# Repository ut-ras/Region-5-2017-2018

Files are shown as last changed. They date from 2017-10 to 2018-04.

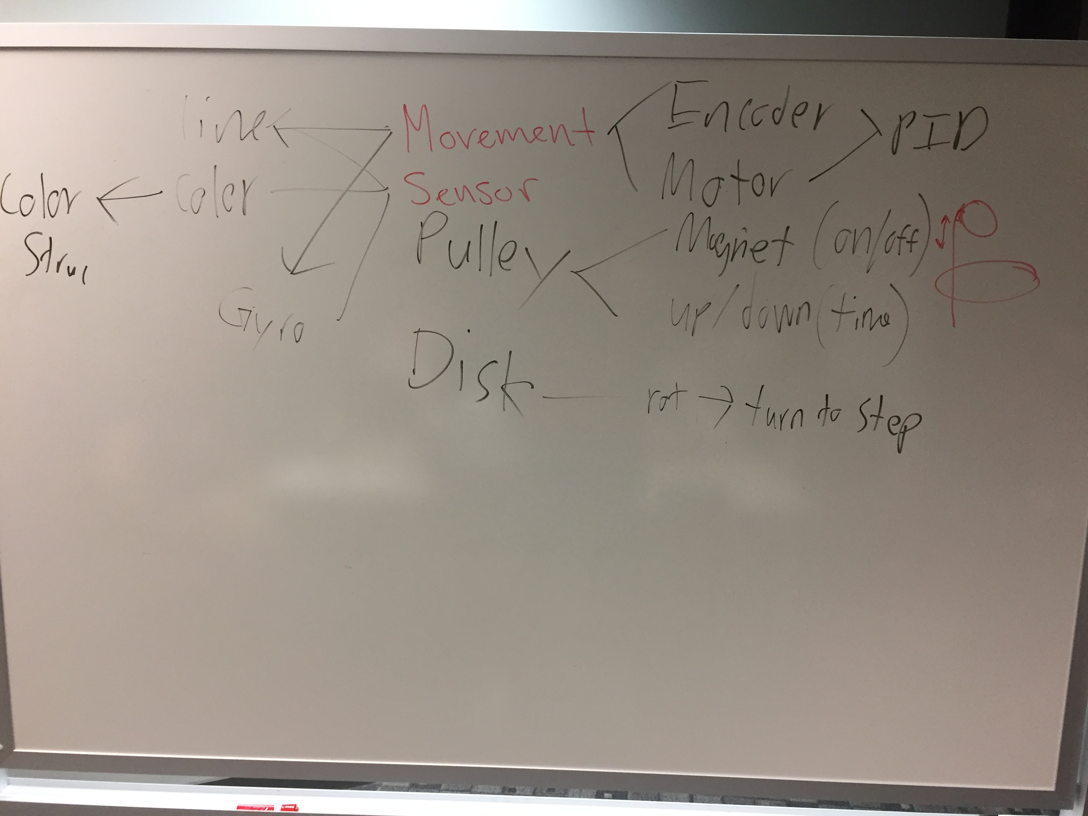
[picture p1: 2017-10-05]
notes/MeetingNotes.JPG

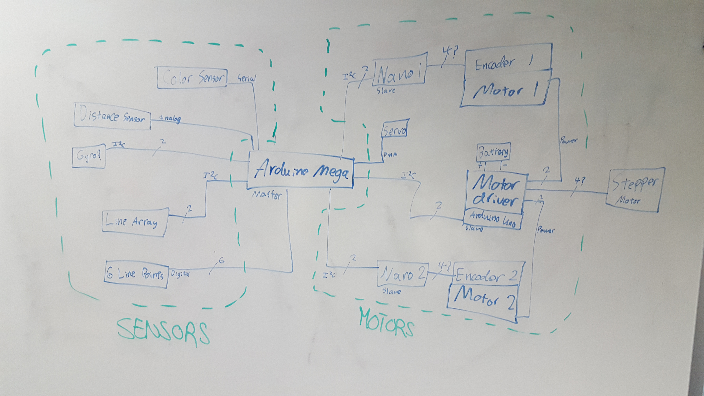
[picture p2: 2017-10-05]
notes/Systems diagram.jpg

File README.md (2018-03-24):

# Region 5 2017-2018
## [Region 5 Robotics Competition](http://r5conferences.org/competitions/robotics-competition/)

### This year we are using the Arduino IDE to program our microcontrollers.
#### [install link](https://www.arduino.cc/en/Main/Software)
#### To set up your laptop:
#### 0. Install the Arduino IDE
#### 1. Clone the Repository
#### 2. Add all the libraries in the ./src/librares/ folder through the arduino IDE
### The lead of Software is Cole Thompson

# Region-5-2017-2018

## WE'RE GONNA <s>WIN</s> MEME THIS YEAR FOLKS

## YEAH WE ARE!!!

## Groups
Drive System</br>
Line Following and Intersection Detection</br>
Token Control and Storage</br>
Field Mapping, Data Logging, and Debugging </br>

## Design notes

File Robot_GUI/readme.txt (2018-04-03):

Robot GUI

Note that an external jar is used, which is included in the jars folder.
Must be connected to Arduino to run.

To compile:
javac -cp ".:../jars/jSerialComm-1.3.11.jar" Robot_GUI.java

To run:
java -cp ".:../jars/jSerialComm-1.3.11.jar" Robot_GUI

This GUI accepts commands in the format of the node.toString() method.
It ignores anything else printed to Serial.

It can also write ints to Serial, however this functionality is untested.

[intersectionName:visited:tokenColor]
ex. [Y3:f:U]

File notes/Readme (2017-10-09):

***************************
*  October 4 - Wednesday  *
*  Header File Plan       *
***************************

Line Sensors
  6 points
     boolean
     
Stepper
  ? angle
  
2 Line
  boolean[8]
  
Ultrasound
  dist cm
  
RGB Sensor
  get a color cloest to...
    green
    red
    yellow
    cyan
    dark blue
    magenta
    
    black
    white
    gray
  
DC Motors
  adafruit motor controller
  speed
  direction
  time
  
Encoder
  # of ticks relative
  
IMU
  gyro
  acc
  compass

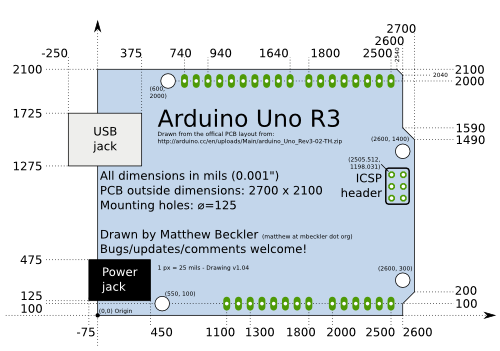
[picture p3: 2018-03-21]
electronics/arduino_uno_drawing_500x351.png

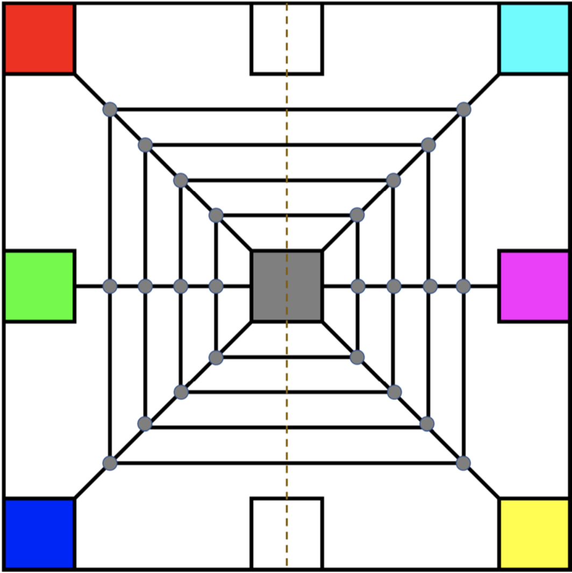
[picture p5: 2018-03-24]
Robot_GUI/playingfield.png

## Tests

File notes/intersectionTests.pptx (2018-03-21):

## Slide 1

Diagonals and Drop Points

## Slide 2

Reversed

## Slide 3

Inward Spiral (Edges)

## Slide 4

Outward Spiral (Edges)

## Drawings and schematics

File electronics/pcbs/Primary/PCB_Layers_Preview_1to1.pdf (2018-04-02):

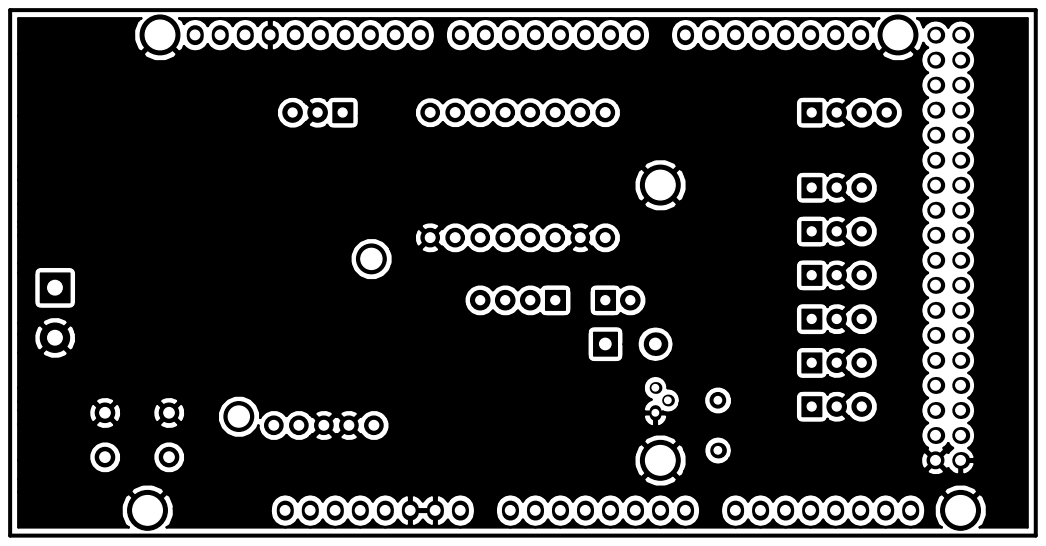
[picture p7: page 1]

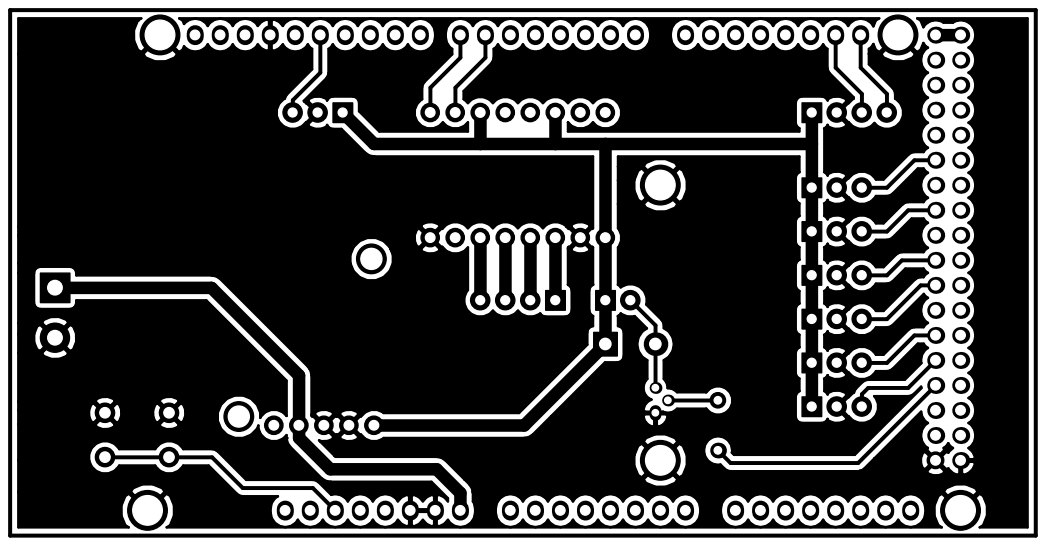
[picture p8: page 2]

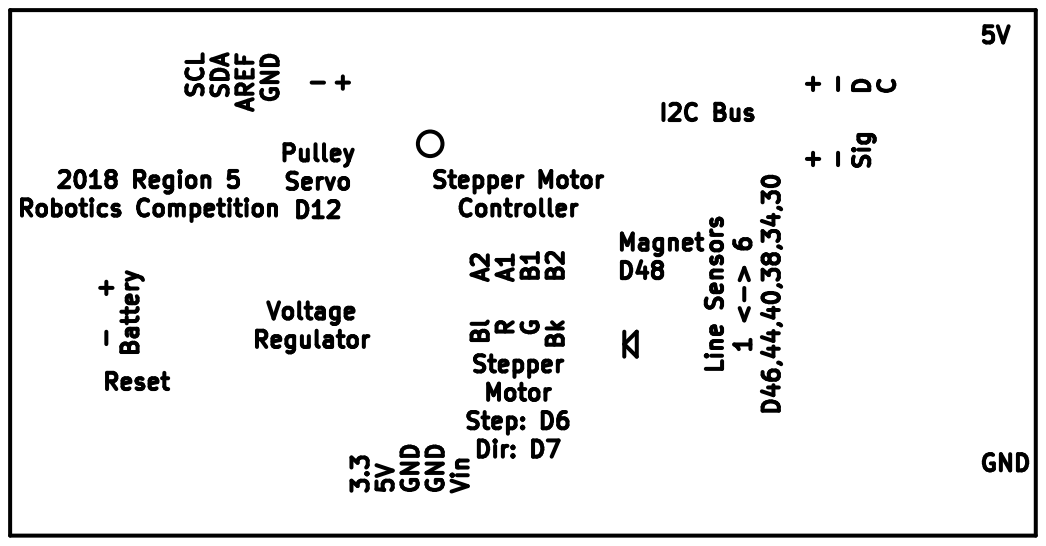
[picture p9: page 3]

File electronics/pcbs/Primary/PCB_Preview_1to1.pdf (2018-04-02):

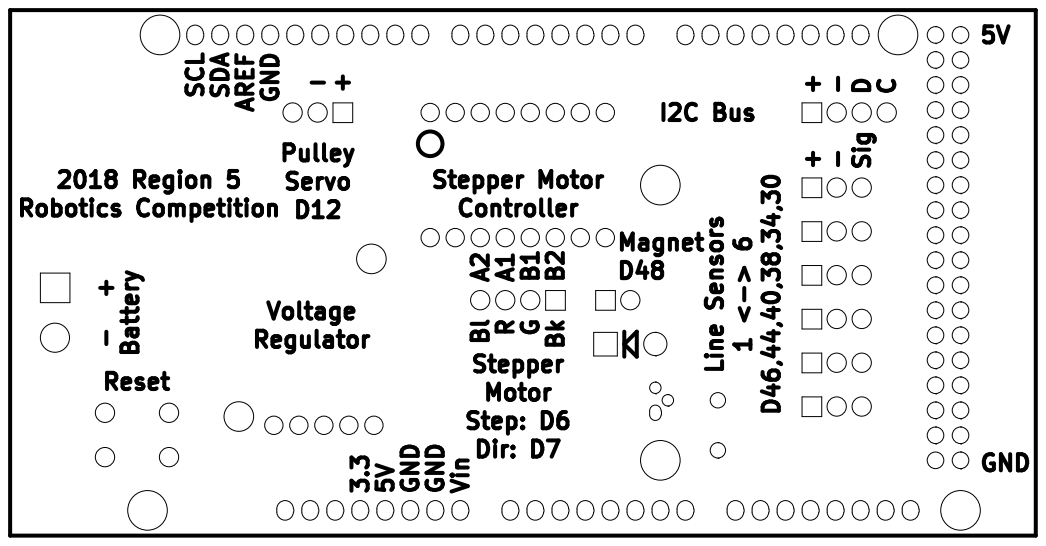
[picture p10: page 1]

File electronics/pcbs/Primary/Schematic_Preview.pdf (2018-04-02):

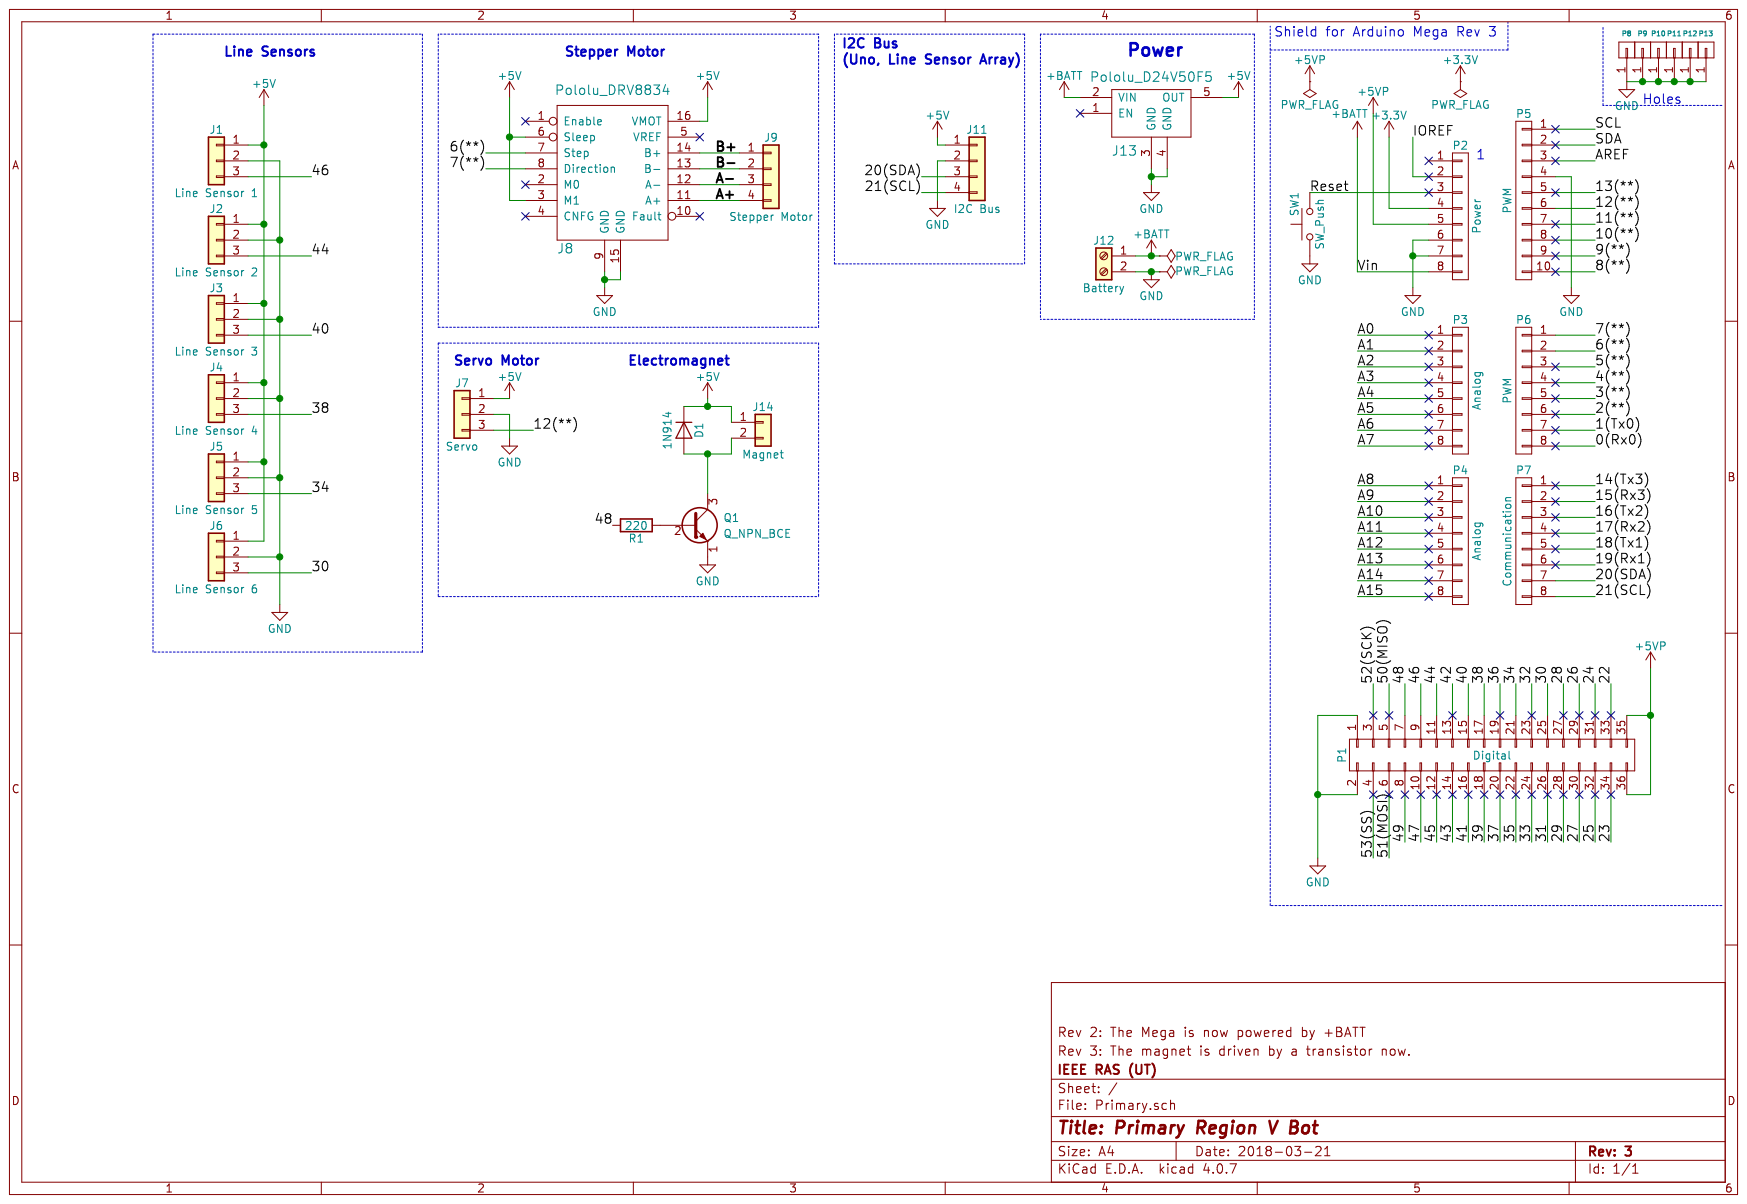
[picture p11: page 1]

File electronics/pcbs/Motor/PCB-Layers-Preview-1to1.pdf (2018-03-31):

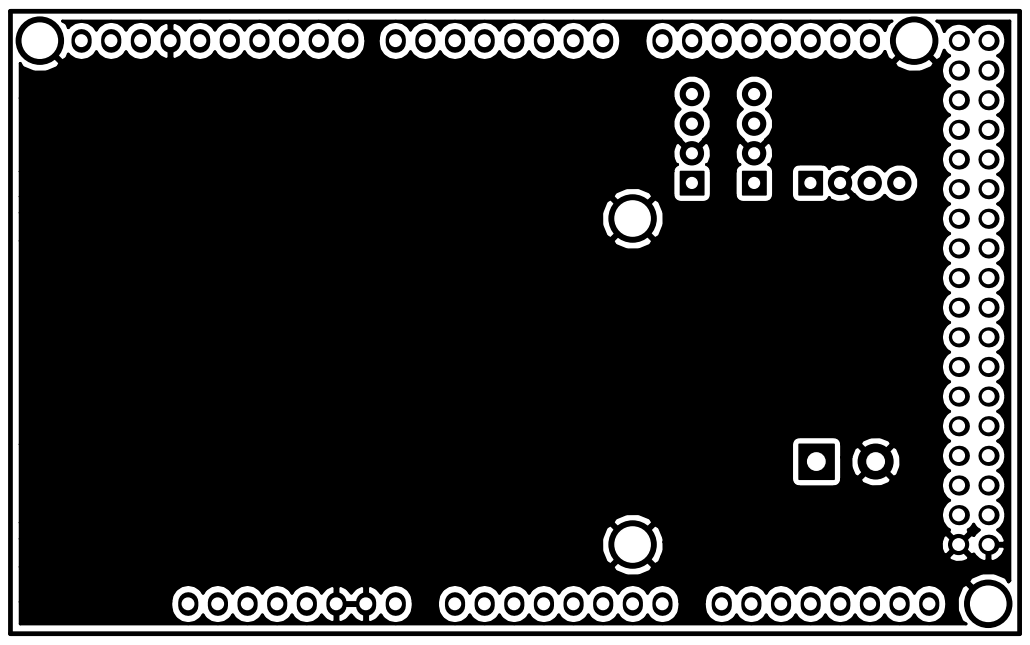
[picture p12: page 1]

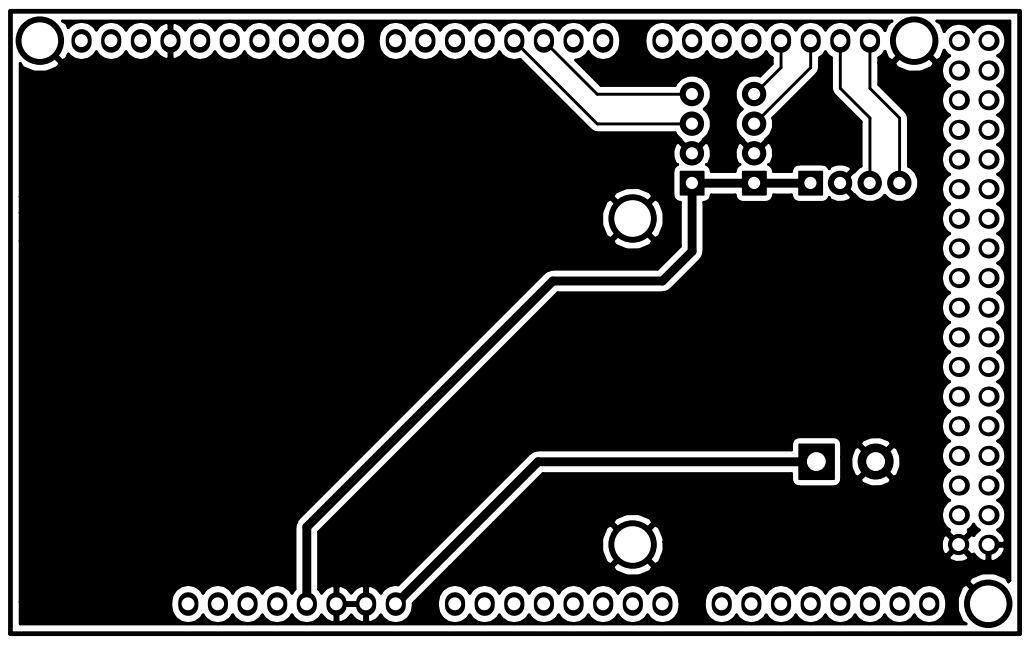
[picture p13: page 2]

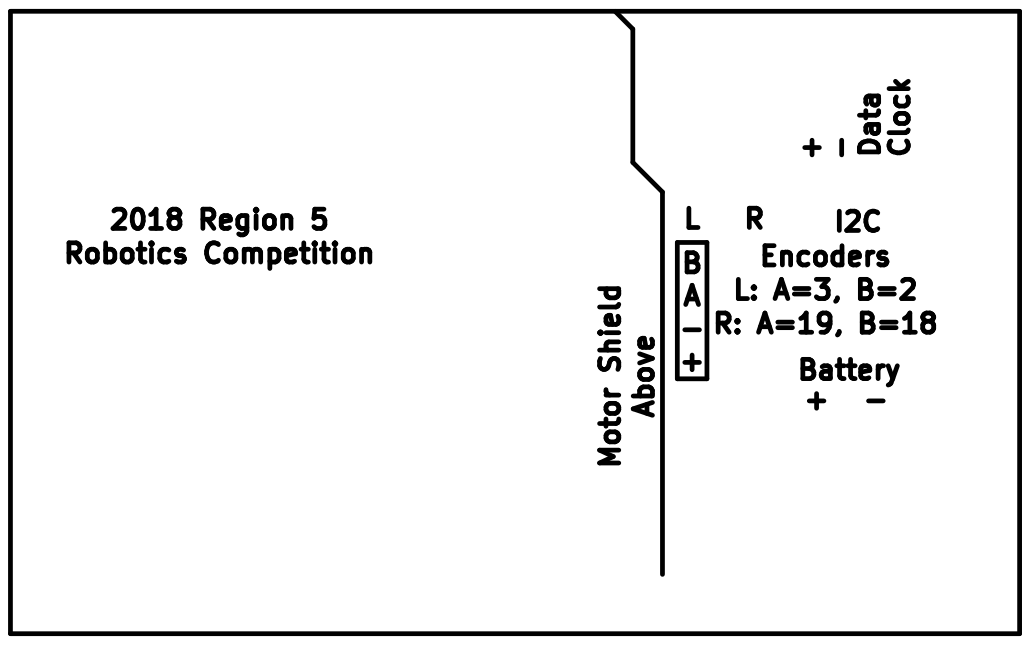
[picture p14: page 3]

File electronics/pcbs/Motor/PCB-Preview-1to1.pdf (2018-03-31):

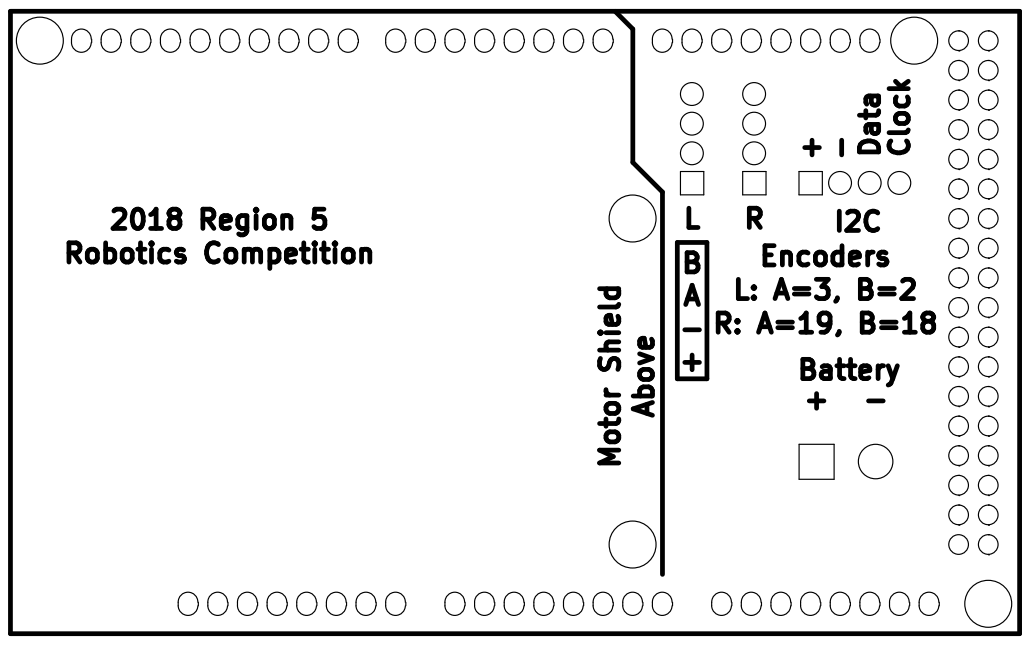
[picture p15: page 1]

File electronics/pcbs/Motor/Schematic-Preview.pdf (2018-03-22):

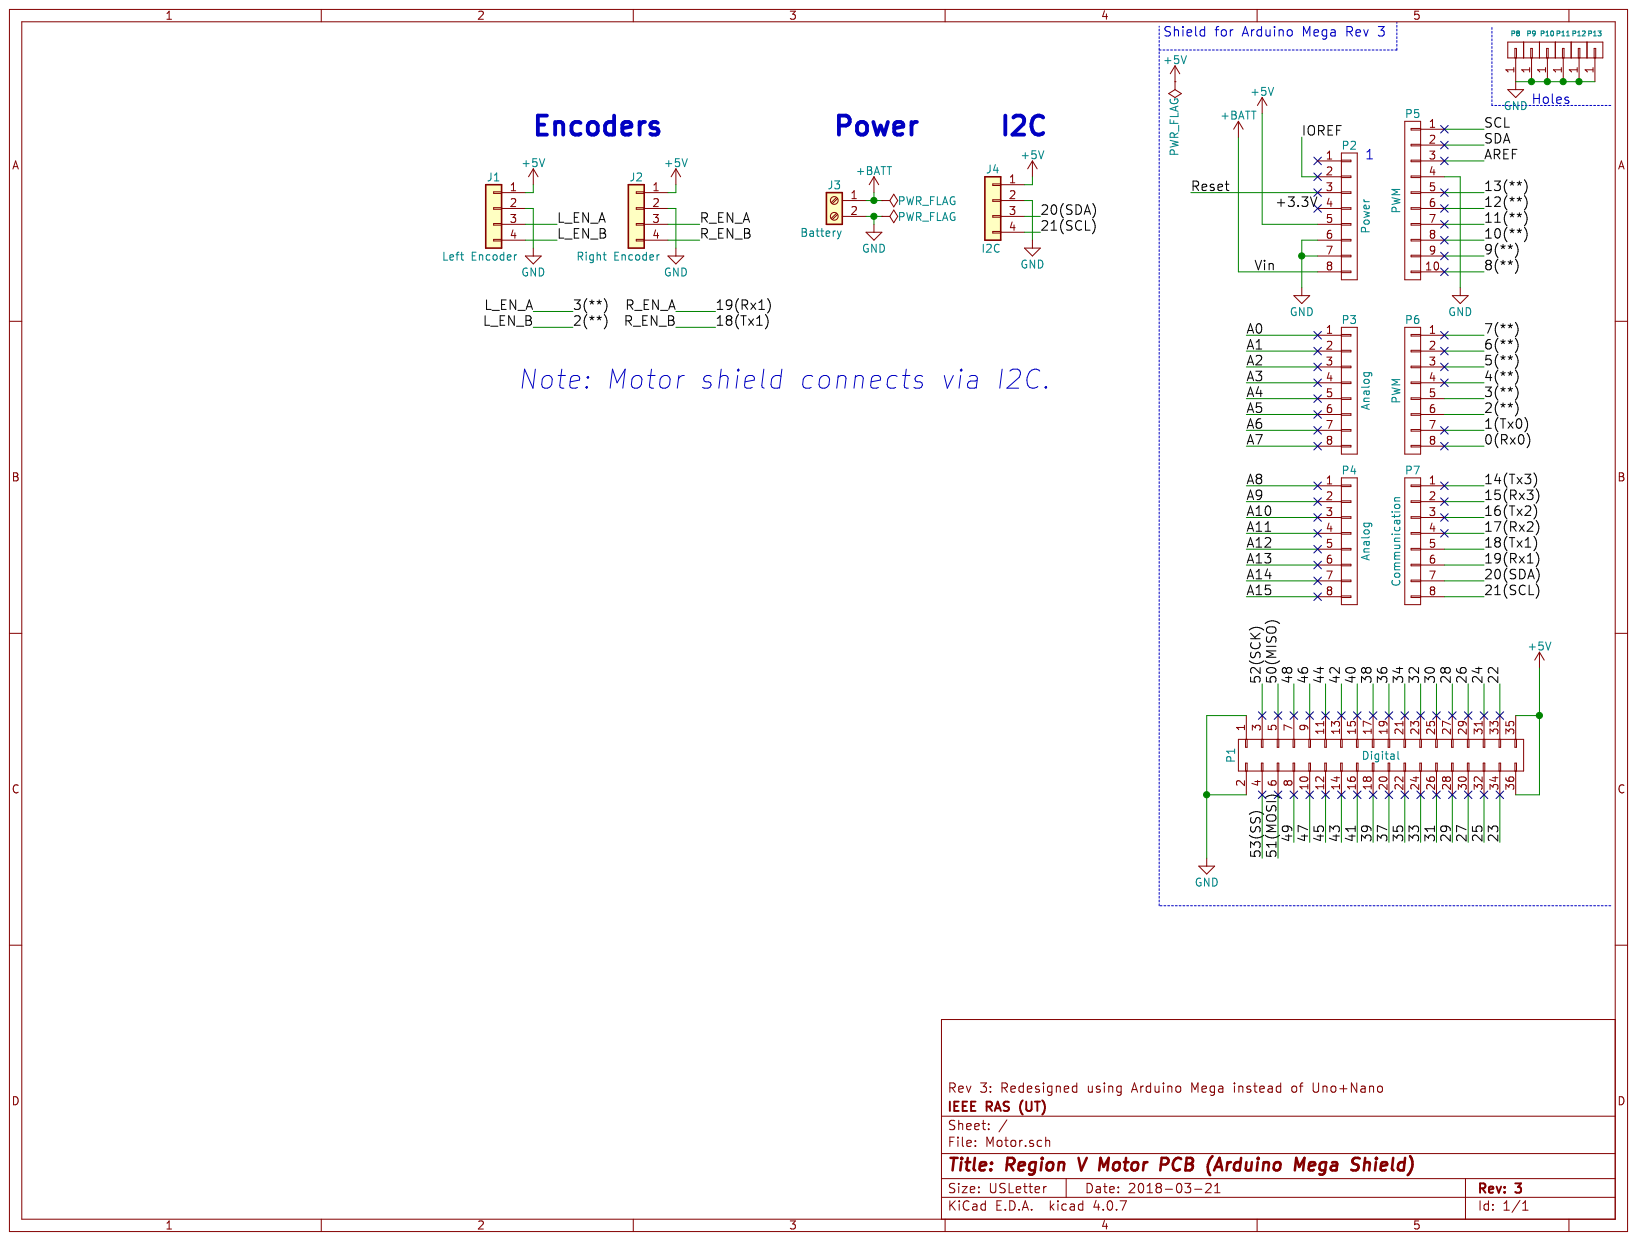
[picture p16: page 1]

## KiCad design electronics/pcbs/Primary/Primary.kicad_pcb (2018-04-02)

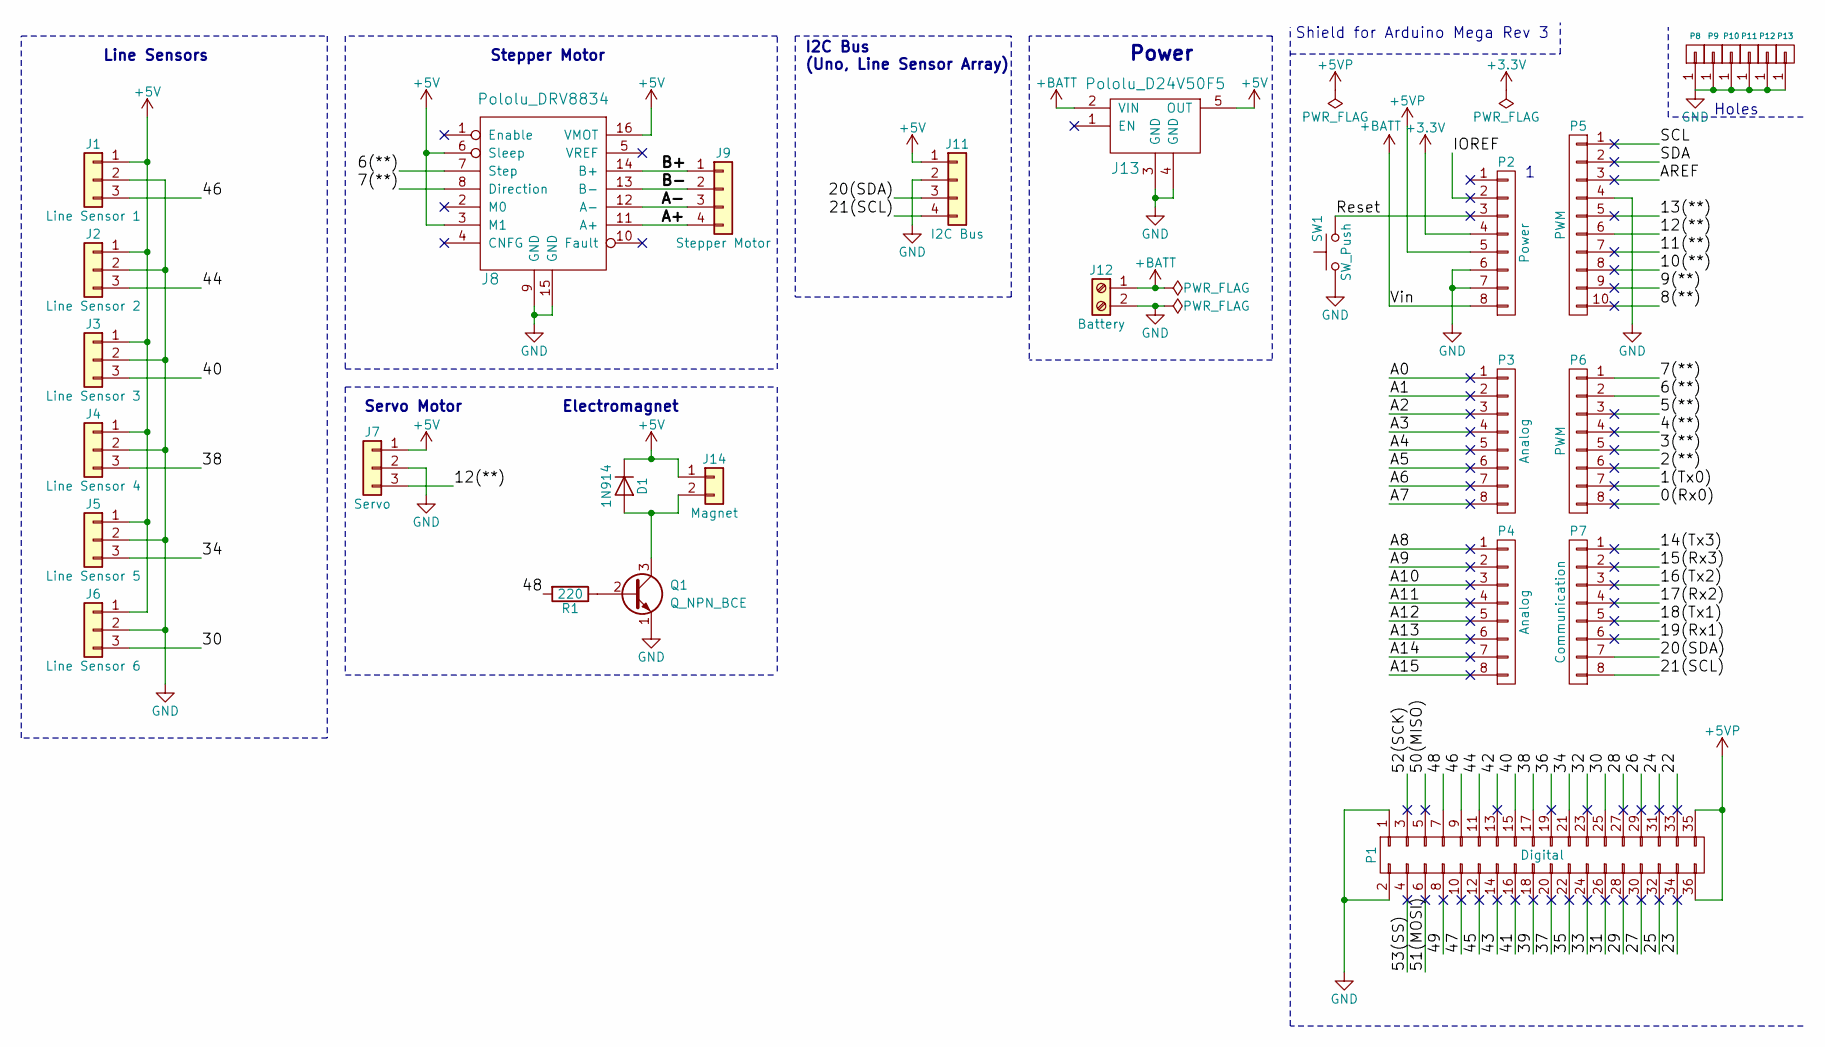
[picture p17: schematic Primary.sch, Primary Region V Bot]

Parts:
D1: 1N914; D_DO-15_P5.08mm_Vertical_KathodeUp
J1: Line Sensor 1; SL-103-X-XX_1x03
J2: Line Sensor 2; SL-103-X-XX_1x03
J3: Line Sensor 3; SL-103-X-XX_1x03
J4: Line Sensor 4; SL-103-X-XX_1x03
J5: Line Sensor 5; SL-103-X-XX_1x03
J6: Line Sensor 6; SL-103-X-XX_1x03
J7: Servo; SL-103-X-XX_1x03
J8: Pololu_DRV8834
J9: Stepper Motor; SL-104-X-XX_1x04
J11: I2C Bus; SL-104-X-XX_1x04
J12: Battery; TerminalBlock_bornier-2_P5.08mm
J13: Pololu_D24V50F5
J14: Magnet; SL-102-X-XX_1x02
P1: Digital; Socket_Strip_Arduino_2x18
P2: Power; Socket_Strip_Arduino_1x08
P3, P4: Analog; Socket_Strip_Arduino_1x08
P5: PWM; Socket_Strip_Arduino_1x10
P6: PWM; Socket_Strip_Arduino_1x08
P7: Communication; Socket_Strip_Arduino_1x08
P8, P9, P10, P11, P12, P13: CONN_01X01; Arduino_1pin
Q1: Q_NPN_BCE; TO-18-3
R1: 220; R_Axial_DIN0309_L9.0mm_D3.2mm_P5.08mm_Vertical
SW1: SW_Push; SW_PUSH_6mm_h4.3mm

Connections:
+3V3: P2.4
+5V: D1.1 (K), J1.1, J2.1, J3.1, J4.1, J5.1, J6.1, J7.1, J8.3 (M1), J8.6 (Sleep), J8.16 (VMOT), J11.1, J13.5 (OUT), J14.1
+5VP: P1.35, P1.36, P2.5
+BATT: J12.1, J13.2 (VIN), P2.8
/0(Rx0): P6.8
/1(Tx0): P6.7
/2(**): P6.6
/3(**): P6.5
/4(**): P6.4
/5(**): P6.3
/6(**): J8.7 (Step), P6.2
/7(**): J8.8 (Direction), P6.1
/8(**): P5.10
/9(**): P5.9
/10(**): P5.8
/11(**): P5.7
/12(**): J7.3, P5.6
/13(**): P5.5
/14(Tx3): P7.1
/15(Rx3): P7.2
/16(Tx2): P7.3
/17(Rx2): P7.4
/18(Tx1): P7.5
/19(Rx1): P7.6
/20(SDA): J11.3, P7.7
/21(SCL): J11.4, P7.8
/22: P1.33
/23: P1.34
/24: P1.31
/25: P1.32
/26: P1.29
/27: P1.30
/28: P1.27
/29: P1.28
/30: J6.3, P1.25
/31: P1.26
/32: P1.23
/33: P1.24
/34: J5.3, P1.21
/35: P1.22
/36: P1.19
/37: P1.20
/38: J4.3, P1.17
/39: P1.18
/40: J3.3, P1.15
/41: P1.16
/42: P1.13
/43: P1.14
/44: J2.3, P1.11
/45: P1.12
/46: J1.3, P1.9
/47: P1.10
/48: P1.7, R1.2
/49: P1.8
/50(MISO): P1.5
/51(MOSI): P1.6
/52(SCK): P1.3
/53(SS): P1.4
/A0: P3.1
/A1: P3.2
/A2: P3.3
/A3: P3.4
/A4: P3.5
/A5: P3.6
/A6: P3.7
/A7: P3.8
/A8: P4.1
/A9: P4.2
/A10: P4.3
/A11: P4.4
/A12: P4.5
/A13: P4.6
/A14: P4.7
/A15: P4.8
/A+: J8.11 (A+), J9.4
/A-: J8.12 (A-), J9.3
/AREF: P5.3
/B+: J8.14 (B+), J9.1
/B-: J8.13 (B-), J9.2
/IOREF: P2.2
/Reset: P2.3, SW1.2
/SCL: P5.1
/SDA: P5.2
GND: J1.2, J2.2, J3.2, J4.2, J5.2, J6.2, J7.2, J8.9 (GND), J8.15 (GND), J11.2, J12.2, J13.3 (GND), J13.4 (GND), P1.1, P1.2, P2.6, P2.7, P5.4, P8.1, P9.1, P10.1, P11.1, P12.1, P13.1, Q1.1 (E), SW1.1
unnamed: D1.2 (A), J14.2, Q1.3 (C)
unnamed: Q1.2 (B), R1.1

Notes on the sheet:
Shield for Arduino Mega Rev 3
Holes
Line Sensors
Stepper Motor
I2C Bus (Uno, Line Sensor Array)
Servo Motor
Power
Electromagnet

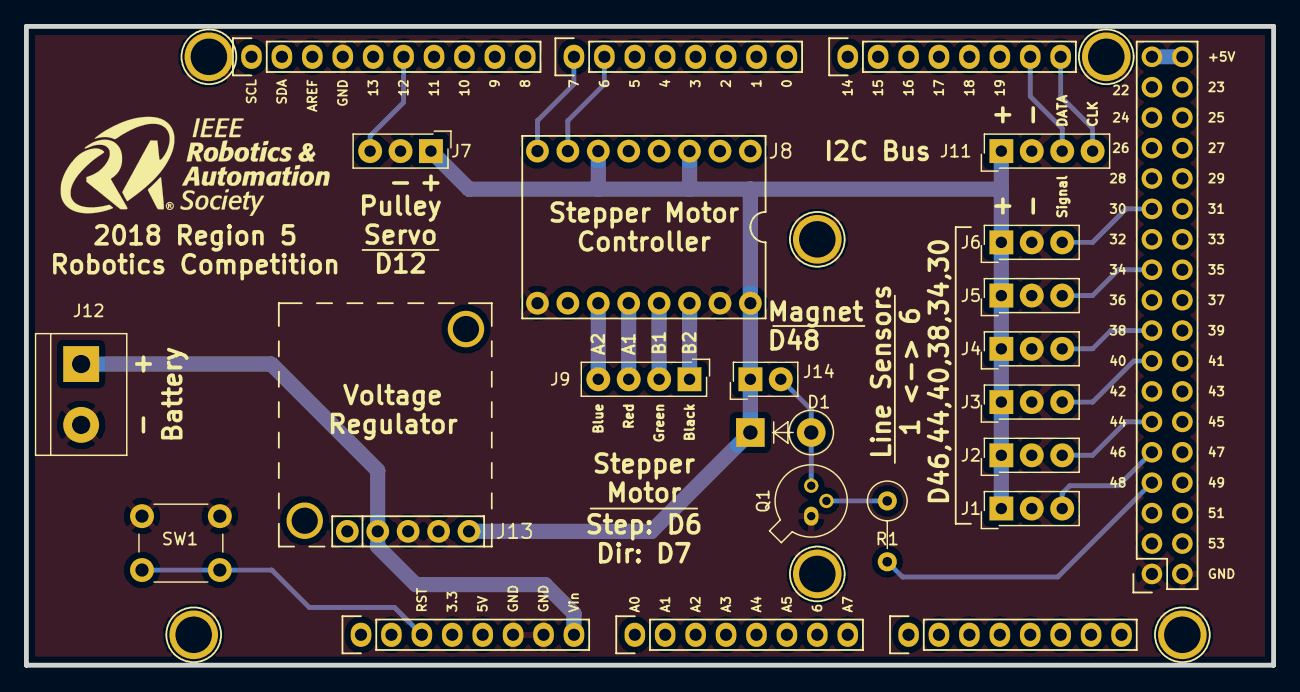
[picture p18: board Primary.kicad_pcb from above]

Board: 2 copper layers, 104.1 x 53.3 mm, 30 parts (0 on the bottom side), 23 nets.

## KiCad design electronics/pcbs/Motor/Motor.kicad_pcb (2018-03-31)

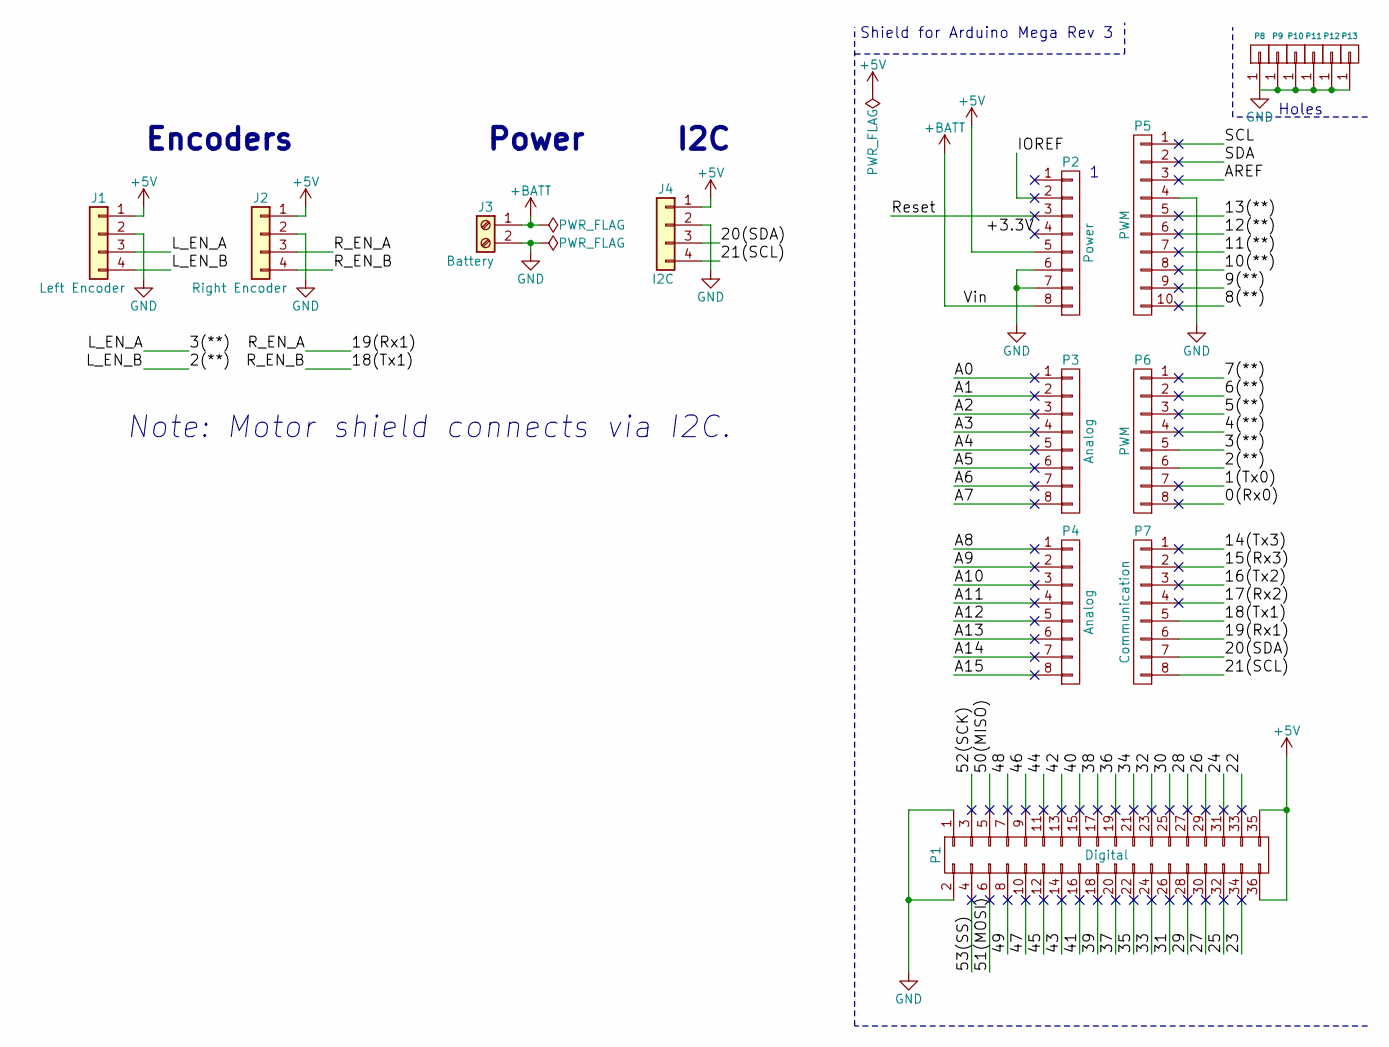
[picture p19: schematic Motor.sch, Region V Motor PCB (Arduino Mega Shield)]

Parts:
J1: Left Encoder; SL-104-X-XX_1x04
J2: Right Encoder; SL-104-X-XX_1x04
J3: Battery; TerminalBlock_bornier-2_P5.08mm
J4: I2C; SL-104-X-XX_1x04
P1: Digital; Socket_Strip_Arduino_2x18
P2: Power; Socket_Strip_Arduino_1x08
P3, P4: Analog; Socket_Strip_Arduino_1x08
P5: PWM; Socket_Strip_Arduino_1x10
P6: PWM; Socket_Strip_Arduino_1x08
P7: Communication; Socket_Strip_Arduino_1x08
P8, P9, P10, P11, P12, P13: CONN_01X01; Arduino_1pin

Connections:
+5V: J1.1, J2.1, J4.1, P1.35, P1.36, P2.5
+BATT: J3.1, P2.8
/0(Rx0): P6.8
/1(Tx0): P6.7
/2(**): J1.4, P6.6
/3(**): J1.3, P6.5
/4(**): P6.4
/5(**): P6.3
/6(**): P6.2
/7(**): P6.1
/8(**): P5.10
/9(**): P5.9
/10(**): P5.8
/11(**): P5.7
/12(**): P5.6
/13(**): P5.5
/14(Tx3): P7.1
/15(Rx3): P7.2
/16(Tx2): P7.3
/17(Rx2): P7.4
/18(Tx1): J2.4, P7.5
/19(Rx1): J2.3, P7.6
/20(SDA): J4.3, P7.7
/21(SCL): J4.4, P7.8
/22: P1.33
/23: P1.34
/24: P1.31
/25: P1.32
/26: P1.29
/27: P1.30
/28: P1.27
/29: P1.28
/30: P1.25
/31: P1.26
/32: P1.23
/33: P1.24
/34: P1.21
/35: P1.22
/36: P1.19
/37: P1.20
/38: P1.17
/39: P1.18
/40: P1.15
/41: P1.16
/42: P1.13
/43: P1.14
/44: P1.11
/45: P1.12
/46: P1.9
/47: P1.10
/48: P1.7
/49: P1.8
/50(MISO): P1.5
/51(MOSI): P1.6
/52(SCK): P1.3
/53(SS): P1.4
/+3.3V: P2.4
/A0: P3.1
/A1: P3.2
/A2: P3.3
/A3: P3.4
/A4: P3.5
/A5: P3.6
/A6: P3.7
/A7: P3.8
/A8: P4.1
/A9: P4.2
/A10: P4.3
/A11: P4.4
/A12: P4.5
/A13: P4.6
/A14: P4.7
/A15: P4.8
/AREF: P5.3
/IOREF: P2.2
/Reset: P2.3
/SCL: P5.1
/SDA: P5.2
GND: J1.2, J2.2, J3.2, J4.2, P1.1, P1.2, P2.6, P2.7, P5.4, P8.1, P9.1, P10.1, P11.1, P12.1, P13.1

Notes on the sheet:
Shield for Arduino Mega Rev 3
Holes
Encoders
Power
I2C
Note: Motor shield connects via I2C.

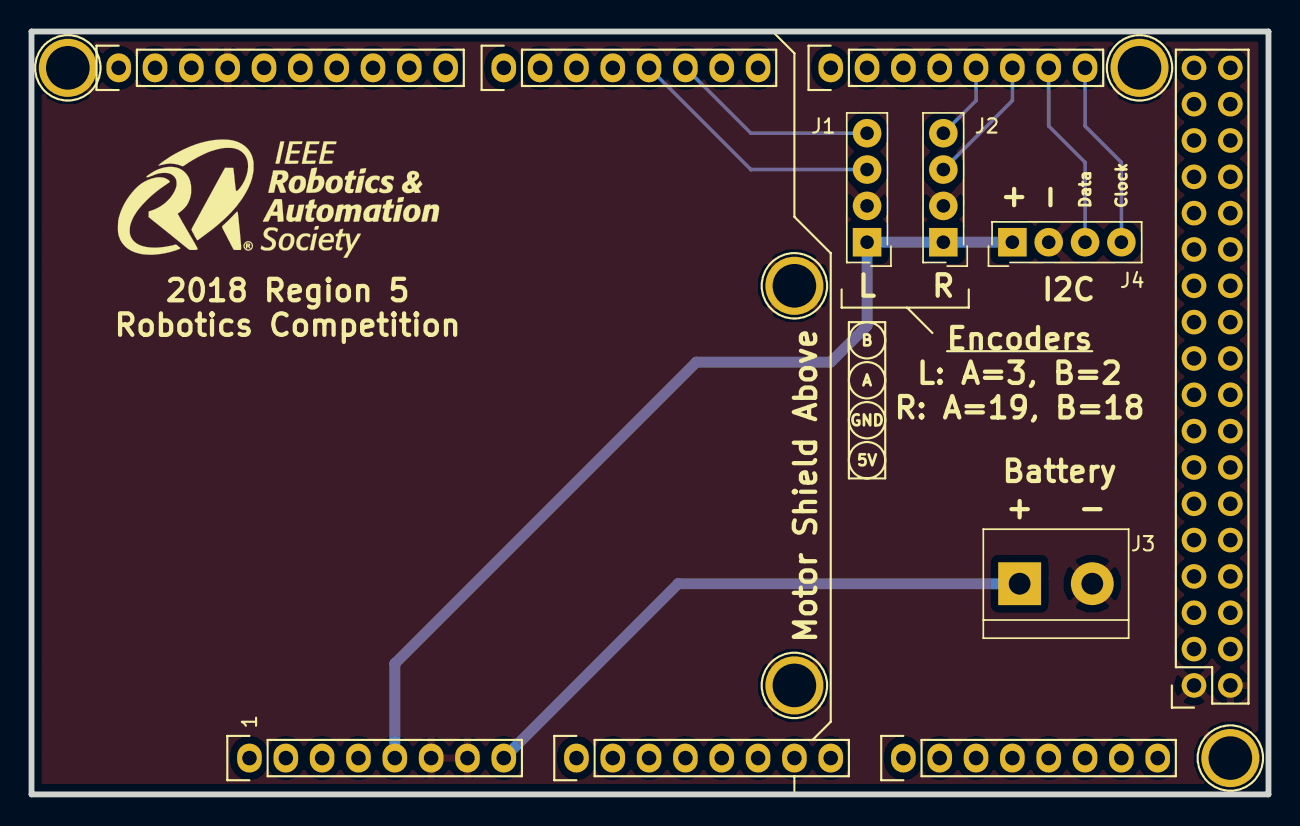
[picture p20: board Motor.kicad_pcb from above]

Board: 2 copper layers, 86.5 x 53.3 mm, 16 parts (0 on the bottom side), 9 nets.

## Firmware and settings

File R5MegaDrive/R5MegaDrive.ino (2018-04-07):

#include "MotorControl.h"
#include <Arduino.h>

//required libraries: Adafruit_MotorShield v2, PID by Brett, SparkFun Line Follower Array, QTRSensors

#define DRIVE_MEGA_I2C 8

#define ENCODER_L_A 3
#define ENCODER_L_B 2
#define ENCODER_R_A 19
#define ENCODER_R_B 18

MotorControl * m;
encoder* leftEncoder;
encoder* rightEncoder;
void  initMotorControl();
void  initI2c();
//int isrCount[2] = {0, 0};
int8_t newCommand = -1;


const int stopButton = 51;
const int startButton = 52;


void checkStop() {
  if (digitalRead(stopButton) == 0) {
    Serial.println("Stop button");
    m->setMotorSpeeds(0, 0);
    while(true);
  }
  Serial.println("Not Stop Button");
}

void setup() {
  Serial.begin(9600);  // start serial for testing outputs
  delay(1000);

  pinMode(stopButton, INPUT_PULLUP);
  pinMode(startButton, INPUT_PULLUP);

  Serial.println("welcome to this test");

  initI2c();

  initMotorControl();
  Serial.println("setup i2c");

  //these will halt the program and print best values when done
  //use one at a time. P, set P in MotorControl, I, set I in MotorControl
  //we can tune on the field by running this, then plug into serial to see result
  //args: (min, max, step)
  //m->sweepPValues(.1, .8, .05);
  //m->sweepIValues(15, 20, 1);

  Serial.println("end of setup - drive mega main");


  //test
  m->setMotorMode(STOP);

  emergencyRound1();
}

void loop() {
  //test different loop delays, LOOP_DELAY in MotorControl.h
  checkStop();
  delay(LOOP_DELAY);

  m->updateMotorControl();
  m->serialDebugOutput(false);    //debugging

  //encoder check
  //Serial.println("left encoder isr " + String(isrCount[0]) + " / right encoder isr " + String(isrCount[1]));
  //Serial.println("left encoder position " + String(leftEncoder->getPos()) + " / right encoder position" + String(rightEncoder->getPos()));

  checkStop();
  
  if (newCommand >= 0) {
    Serial.println("New Command: " + String(newCommand));
    m->setMotorMode(newCommand);
    newCommand = -1;
  }
  
}


void emergencyRound1() {
  int wait = 15000;
  
  Serial.println("Hello");
  while(digitalRead(startButton) == 1){
    delay(100);
    checkStop();
  }

  m->setMotorMode(FWDNOLINE);
  long t = millis() + wait;
  Serial.println("FWD");  
  while(millis() < t) {
    checkStop();
    m->updateMotorControl();
    delay(LOOP_DELAY);
  }
  
  m->setMotorMode(STOP);
   t = millis() + wait - 1000;
  Serial.println("STOP");
  while(millis() < t) {
    checkStop();
    m->updateMotorControl();
    delay(LOOP_DELAY);
  }

  m->setMotorMode(BACKNOLINE);
   t = millis() + wait - 500;
   Serial.println("BACK");
  while(millis() < t) {
    checkStop();
    m->updateMotorControl();
    delay(LOOP_DELAY);
  }
  m->setMotorMode(STOP);

  Serial.println("Hello");
}



//REQUIRED MAIN METHOD FUNCTIONS FOR MOTOR CONTROL BELOW

// function that executes whenever data is received from master
// this function is registered as an event, see setup()
void receiveEvent(int howMany) {
    Serial.println("recieve");
    int8_t c = Wire.read();      // receive byte as a character
    newCommand = c;
}

void initI2c() {
  //I2C Initialization
  Wire.begin(DRIVE_MEGA_I2C);
  Wire.onReceive(receiveEvent);
}

void initMotorControl() {
  m = new MotorControl(ENCODER_L_A, ENCODER_L_B, ENCODER_R_A, ENCODER_R_B);
  Serial.println("created motor control");
  m->setMotorMode(STOP);

  leftEncoder = m->getLeftEncoder();
  rightEncoder = m->getRightEncoder();

  attachInterrupt(digitalPinToInterrupt(ENCODER_L_A), leftEncoderISR, CHANGE);
  attachInterrupt(digitalPinToInterrupt(ENCODER_R_A), rightEncoderISR, CHANGE);

  Serial.println("motor control initialized in main");
}

void leftEncoderISR() {
  //isrCount[0]++;
  leftEncoder->updatePos();
}

void rightEncoderISR() {
  //isrCount[1]++;
  rightEncoder->updatePos();
}

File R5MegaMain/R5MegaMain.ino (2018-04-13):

#include <Time.h>
#include <Arduino.h>

#include "src/control/tokenControl.h"
#include "src/control/driveControl.h"
#include "src/control/Graph.h"

#define MAIN_MEGA_I2C 0x10

/* Required libraries (sketch/include library/manage libraries to add)
 * Adafruit_TCS34725
 */

#define FWD true

//TODO: Change the button pin numbers to the appropriate pins
//const int startButton = 2;
//const int stopButton = 3;

tokenControl *tokenController;
driveControl *driveController;
Graph * mapGraph;

/* void waitForStart() {
  //While not pressed
  while(digitalRead(startButton) == 1){
    delay(100);
  }
  //send i2c to main
}

void stopISR(){
  while(true);
}*/

void setup() {
  // put your setup code here, to run once:]
  Serial.begin(9600);

  //Negative Logic Buttons
  //pinMode(startButton, INPUT_PULLUP);
  //pinMode(stopButton, INPUT_PULLUP);
  //attachInterrupt(digitalPinToInterrupt(stopButton), stopISR, FALLING);
  
  mapGraph = new Graph();
  tokenController = new tokenControl(mapGraph);
  driveController = new driveControl(mapGraph);

  driveController->sendCommand(STOP);
    
  Wire.begin();

  //waitForStart();

  //mapGraph->printSerial();

  delay(2000);
  //testTokenControl();
  //printIntersectionData();
  //testDriveControl();
  //testGUI();
  //testCombo();
  testSimple();

}

void loop() {
  // put your main code here, to run repeatedly:
  Blink();
  round1();
}

//debugging gui
/*void serialEvent() {
  while (Serial.available()) {
    // get the new byte:
    int8_t inChar = Serial.parseInt();
    if ((inChar >= 0) && (inChar <= STOP)) {
      driveController->sendCommand(inChar);
    }
  }
}*/

void testCombo() {
  Blink();
  driveController->sendCommand(STOP);
  while(1){
    for(int i = 0; i < 2; i ++){
      driveController->sendCommand(STOP);
      tokenController->pickUpToken();
      driveController->forwardToIntersection();
    }
    tokenController->pickUpToken();
    driveController->turnManeuver(true, 2);
  }
}

void testTokenControl() {
  Blink();
  //tokenController->goToEveryColour();
  //tokenController->depositTokens(magenta);
    Serial.println("Start");
    //tokenController->readColour();
    //tokenController->pickUpToken(); 
    //Serial.println("----");
    //Serial.println("");
    delay(2000);
    while(1){
    //tokenController->readColour();
    //tokenController->pickUpToken(); 
    tokenController->pickUpToken(); 
    Serial.println("----");
    Serial.println("");
    delay(5000);
    }
}
      
void Blink(){
  digitalWrite(LED_BUILTIN, HIGH);
  delay(1000);
  digitalWrite(LED_BUILTIN, LOW);
  delay(1000);
}

void testDriveControl() {
  //driveController->move(true);

  driveController->setSpeed(2);
  
  setCurrentLocationForTest(R5, 4);  
  Serial.println(mapGraph->getCurrentNode()->toString());
  driveController->forwardToIntersection();
  tokenController->pickUpToken();
  driveController->setSpeed(2);
  Serial.println(mapGraph->getCurrentNode()->toString());
  delay(3000);
  driveController->forwardToIntersection();
  tokenController->pickUpToken();
  driveController->setSpeed(2);
  Serial.println(mapGraph->getCurrentNode()->toString());
  delay(3000);
  driveController->turn45(true, 2);
  driveController->forwardToIntersection();
  tokenController->pickUpToken();
  driveController->setSpeed(2);
  
}

//where the bot is starting, (location, dir)
void setCurrentLocationForTest(int name, int dir) {
  mapGraph->setCurrentNode(mapGraph->getNode(name));
  mapGraph->setCurrentDirection(dir);
  Serial.println("set node to " + String(mapGraph->getNode(name)->toString())+ " set direction to " + String(mapGraph->getCurrentDirection()));
}

void printIntersectionData() {
  intersectionSensors * s = driveController->getIntersectionSensors();
  while(1) {
    Serial.println(s->getData().toString());
    delay(500);
  }
}

/*
 * Coded by Catherine, Colton
 * Commented code with "//" - is asumming we do not need
 *                            but might need in the future
 * CHECK delay(1000) - is this the correct parameters?
 *                     delay is there for the robot to move
 *                       inside the colored box
 */

//Useful Function Prototypes:
void dropOffTokens(int color, int level);
void red2cyan(bool collectTokens);
void red2green(bool collectTokens);
void green2red(bool collectTokens);
void green2blue(bool collectTokens);
void blue2green(bool collectTokens);
void blue2yellow(bool collectTokens);
void yellow2blue(bool collectTokens);
void yellow2magenta(bool collectTokens);
void magenta2yellow(bool collectTokens);
void magenta2cyan(bool collectTokens);
void cyan2magenta(bool collectTokens);
void cyan2red(bool collectTokens);
void color2grey(int colorStart, bool collectTokens);
void grey2color(int colorEnd, bool collectTokens);
void goColor2Color(int colorStart, int colorEnd, bool tokenCollect);
void changeLevel(int color, int startLevel, int endLevel);


void testGUI(){
  setCurrentLocationForTest(Y4, 2);
  driveController->turnTo(0);
  driveController->forwardToIntersection(); //magenta;
  driveController->forwardToIntersection(); //cyan;
  driveController->turnTo(6);
  driveController->forwardToIntersection(); //red;
  goColor2Color(red, blue, true);
  changeLevel(blue, 4, 2);
  goColor2Color(blue, cyan, true);

}


void testSimple() {

  driveController->forwardAtStart();  
  Serial.println("hit the white box edge");
  driveController->forwardAtStart();
  Serial.println("hit the first square line");
  driveController->forwardAtStart();
  Serial.println("hit the second square line");
  driveController->forwardAtStart();  
  Serial.println("hit the third square line");
  driveController->forwardAtStart();
  Serial.println("hit the fourth box line");
  driveController->turn45(true, 2);
  Serial.println("turn to the left (toward blue)");

  setCurrentLocationForTest(Y4, 6);
  Serial.println(mapGraph->getCurrentNode()->toString());
  driveController->forwardToIntersection();
  Serial.println("drive to Blue 4");
  tokenController->pickUpToken();
  Serial.println("pick up the token");
  driveController->turn45(true, 1);
  Serial.println("turn towards blue box");
  //setCurrentLocationForTest(Bl4, 5);  //redundant
  driveController->forwardToIntersection();
  Serial.println("drive to Blue 3");
  driveController->forwardToIntersection();   //drive to Bl2
  Serial.println("drive to Blue 2");
  tokenController->pickUpToken();
  Serial.println("pick up the token");
  dropOffTokens(blue, 2);
  Serial.println("drop off in blue");
}
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

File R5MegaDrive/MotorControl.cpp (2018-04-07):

    #include "MotorControl.h"

    #include <Arduino.h>
    #include <Adafruit_MotorShield.h>
    #include <PID_v1.h>
    #include "utility/Adafruit_MS_PWMServoDriver.h"

    MotorControl::MotorControl(int lA, int lB, int rA, int rB) {
      //Field Initializations

      l_Encoder = new encoder(lA, lB);
      r_Encoder = new encoder(rA, rB);

      //Serial.println("inside init");

      AFMS = new Adafruit_MotorShield();

      r_Motor = AFMS->getMotor(3);
      l_Motor = AFMS->getMotor(4);

      //Serial.println("AFMS init");

      l_correction = 0;
      r_correction = 0;

      l_EncoderSpeed = 0;
      r_EncoderSpeed = 0;

      prevTime = 0;

      leftKp = 0.25;
      leftKi = 15;
      leftKd = 0;
      l_PID = new PID(&l_EncoderSpeed, &l_PIDSpeed, &l_SetpointSpeed, leftKp, leftKi, leftKd, DIRECT);

      rightKp = 0.25;
      rightKi = 15;
      rightKd = 0;
      r_PID = new PID(&r_EncoderSpeed, &r_PIDSpeed, &r_SetpointSpeed, rightKp, rightKi, rightKd, DIRECT);

      //Serial.println("PID init");

      //Motor Initialization
      AFMS->begin();  // create with the default frequency 1.6KHz

      l_Motor->setSpeed(10);
      r_Motor->setSpeed(10);
      l_PIDSpeed = 10;
      r_PIDSpeed = 10;

      //PID Initialization
      l_PID->SetSampleTime(5);
      l_PID->SetMode(AUTOMATIC);
      l_PID->SetOutputLimits(0, 255);

      r_PID->SetSampleTime(5);
      r_PID->SetMode(AUTOMATIC);
      r_PID->SetOutputLimits(0, 255);


      lineSensorBack = new arrayline(LS_DIGITAL);
      lineSensorFront = new arrayline(LS_ANALOG);

      //delay for testing purposes
      delay(500);
      //Serial.println("Motor Control Initialized");

      currentCmd = STOP;
      useArray=false;
      startTicks = 0;

      l_SetpointSpeed = 0;
      r_SetpointSpeed = 0;
    }


    //Public Functions

    encoder* MotorControl::getLeftEncoder() {
      return l_Encoder;
    }

    encoder* MotorControl::getRightEncoder() {
      return r_Encoder;
    }

    void MotorControl::updateMotorControl() {      //update motor speeds with PID
      if(useArray==false  && (l_Encoder->getPos() > startTicks+80) )
      {
        useArray=true;
      }
      if (useArray && (currentCmd < FWDNOLINE)) {
        calculateLSCorrections();
        //l_SetpointSpeed += l_correction;
        //r_SetpointSpeed += r_correction;
      }
      if(useArray && FWDNOLINE)
      {

      }
      if (currentCmd != STOP) {
        calculateEncoderSpeeds();
        calculatePIDSpeeds();
        setMotorSpeeds(abs(l_PIDSpeed), abs(r_PIDSpeed));
      }
    }

    void MotorControl::turninPlace(int dir) {    //use Directions enum LEFT or RIGHT
      if (dir == RIGHT) {
        l_Motor->run(FORWARD);
        r_Motor->run(BACKWARD);
      }
      else if (dir == LEFT) {
        l_Motor->run(BACKWARD);
        r_Motor->run(FORWARD);
      }
    }

    void MotorControl::moveStraight(int dir) {              //use Directions enum FWD or BACK
      if (dir == BACK) {
        l_Motor->run(BACKWARD);
        r_Motor->run(BACKWARD);
      }
      else if (dir == FWD) {
        l_Motor->run(FORWARD);
        r_Motor->run(FORWARD);
      }
    }

    void MotorControl::stopMotors(int lastCmd) {
      setMotorSpeeds(0, 0);

      int waitTimeMs = 10;
      int r_pos_s = r_Encoder->getPos();
      int l_pos_s = l_Encoder->getPos();

      int r_pos_last = r_pos_s;
      int l_pos_last = l_pos_s;

      delay(waitTimeMs);
      int r_pos_current = r_Encoder->getPos();
      int l_pos_current = l_Encoder->getPos();

      int loopCount = 0;
      /*
      while ((r_pos_last != r_pos_current) || (l_pos_last != l_pos_current)) {
        r_pos_last = r_pos_current;
        l_pos_last = l_pos_current;
        r_pos_current = r_Encoder->getPos();
        l_pos_current = l_Encoder->getPos();
        delay(waitTimeMs);
      }

      int l_diff = abs(l_pos_current - l_pos_s);
      int r_diff = abs(r_pos_current - r_pos_s);

      Serial.println("encoder overshoot l:" + String(l_diff) + " r:" + String(r_diff) + " loopcount:" + String(loopCount));

      //correct motors
      if ((lastCmd == FWD1) || (lastCmd == FWD2) || (lastCmd == FWD3) || (lastCmd == FWDNOLINE)) {
        setMotorSpeeds(20, 20);
        moveStraight(BACK);

      }
      else if ((lastCmd == BACK1) || (lastCmd == BACK2) || (lastCmd == BACK3)) {
        setMotorSpeeds(20, 20);
        moveStraight(FWD);

      }
      //add if we want correction for the turn functions
      /*else if ((lastCmd == LEFTIP) || (lastCmd == LEFT45) || (lastCmd == LEFT90) || (lastCmd == LEFT135) || (lastCmd == LEFT180)) {

      }
      else if ((lastCmd == RIGHTIP) || (lastCmd == RIGHT45) || (lastCmd == RIGHT90) || (lastCmd == RIGHT135) || (lastCmd == RIGHT180) {

      }
      else {
        return;
        */
    /*  }

      //count encoder ticks for correction
      r_pos_s = r_Encoder->getPos();
      l_pos_s = l_Encoder->getPos();

      while ((abs(l_pos_s - l_pos_current) < l_diff) || (abs(r_pos_s - r_pos_current) < r_diff)) {
        r_pos_current = r_Encoder->getPos();
        l_pos_current = l_Encoder->getPos();

        if (abs(l_pos_s - l_pos_current) > l_diff) {
          l_Motor->setSpeed(0);
        }
        else if (abs(r_pos_s - r_pos_current) > r_diff) {
          r_Motor->setSpeed(0);
        }
        delay(5);
      }
      */

      setMotorSpeeds(0, 0);
    }



    //Private Functions
    //note: switched around corrections for testing while sensor is on rear, so we can move backwards and pretend its going fwd
    void MotorControl::calculateLSCorrections() {
      Serial.println("Line Sensor Corrections");

      //grab fwd vs back and move speed
      bool fwd = (currentCmd >= 0) && (currentCmd <= 2);
      int moveSpeed = 0;
      if (currentCmd % 3 == 0) { moveSpeed = LOW_SPEED; }
      else if (currentCmd % 3 == 1) { moveSpeed = MID_SPEED; }
      else { moveSpeed = HIGH_SPEED; }

      //get both line sensor positions -4000 is left, +4000 is right, 1000 for each sensor
      //int lineSensorWeightBack = lineSensorBack->getLinePosition();
      int lineSensorWeightBack = 0;
      int lineSensorWeightFront = lineSensorFront->getLinePosition();
      Serial.println("front weight: " + String(lineSensorWeightFront) + " / back weight: " + String(lineSensorWeightBack));

      //single sensor
      /*if(lineSensorWeightFront <= -1500) {
        turninPlace(fwd?LEFT:RIGHT);
      }
      else if(lineSensorWeightFront >= 1500) {
        turninPlace(fwd?RIGHT:LEFT);
      }
      else {
        moveStraight(fwd?FWD:BACK);
      }*/
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

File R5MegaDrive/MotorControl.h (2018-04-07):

#ifndef MOTORCONTROL_H
#define MOTORCONTROL_H

#include <Arduino.h>
#include <Adafruit_MotorShield.h>
#include <PID_v1.h>
#include "utility/Adafruit_MS_PWMServoDriver.h"
#include <sensorbar.h>

#include "encoder.h"
#include "arrayline.h"

#define LOOP_DELAY 100

#define LOW_SPEED 50
#define MID_SPEED 90
#define HIGH_SPEED 130

//required libraries: Adafruit_MotorShield v2, PID by Brett, SparkFun Line Follower Array


/* HOW TO USE
 * set up encoder ISR in main for both edges of pin A and call updatePos on the encoder
 * call updateMotorControl in a loop
 * use setMotorMode, move, turn, or stop to control
 *
 * v2 of MotorControl class, motor directions and speed more straightforward
 */


enum Commands{BLANK, FWD1, FWD2, FWD3, BACK1, BACK2, BACK3, LEFTIP, RIGHTIP, FWDNOLINE,BACKNOLINE, LEFT45, LEFT90, LEFT135, LEFT180, RIGHT45, RIGHT90, RIGHT135, RIGHT180, STOP, RETURNWHITELEFT, RETURNWHITERIGHT};    //from i2c
enum Directions{FWD, BACK, LEFT, RIGHT};

class MotorControl {

public:
  MotorControl(int lA, int lB, int rA, int rB);

  //i2c communication byte interpretation
  void setMotorMode(int c);

  void updateMotorControl();      //with PID output
  void forwardToWhite(int dir);
  encoder* getLeftEncoder();     //use this to attatch interrupts to encoder pins in main. call updatePos in ISR
  encoder* getRightEncoder();

  void moveStraight(int dir);             //use Directions enum FWD or BACK
  void turninPlace(int dir);   //use Directions enum LEFT or RIGHT
  void stopMotors(int lastCmd);

  //set desired speeds for PID
  void setSetpointSpeeds(int rotSpeed);                     //deg / sec
  void setSetpointSpeeds(int l_rotSpeed, int r_rotSpeed);   //deg / sec

  void serialDebugOutput(boolean plotter);

  //PID tuning
  void setPValues(double p_val);
  void setIValues(double i_val);

  void sweepPValues(double minP, double maxP, double stepP);
  void sweepIValues(double minI, double maxI, double stepI);

  //turn maneuver
  void turnManeuver(int dir, int num45Deg);
  void moveStraightEncoderTicks(int dir, int encoderTicks);		//move fwd along lines an exact number of encoder encoderTicks
  void turnEncoderTicks(int dir, int encoderTicks);    //use Directions enum LEFT or RIGHT

  void setMotorSpeeds(int l_rotSpeed, int r_rotSpeed);    //set actual speeds, direct output to AFMS motors

private:

  //updateMotorSpeeds functions
  void calculateLSCorrections();
  void calculateEncoderSpeeds();
  void calculatePIDSpeeds();

  int currentCmd;

  //hardware
  Adafruit_MotorShield *AFMS;
  Adafruit_DCMotor *l_Motor;
  Adafruit_DCMotor *r_Motor;
  encoder* l_Encoder;
  encoder* r_Encoder;
  arrayline* lineSensorBack;
  arrayline* lineSensorFront;

  // PID Variables
  PID * l_PID;
  PID * r_PID;
  double leftKp, leftKi, leftKd;
  double rightKp, rightKi, rightKd;

  // rotational speeds between 0 and 255 (deg / sec)
  double  l_EncoderSpeed, r_EncoderSpeed;    //PID input, calculated speed of motors
  double l_SetpointSpeed, r_SetpointSpeed;       //desired v of motors, for PID
  double  l_PIDSpeed, r_PIDSpeed;        //PID output, actual speed input to the motors to reach desired v

  //line sensor correction
  int l_correction, r_correction;
  bool useArray = false;
  int startTicks = 0;

  //encoder vars
  int l_PrevEncoderPos = 0;      //encoder steps
  int r_PrevEncoderPos = 0;
  unsigned long prevTime;   //stored as milliseconds, converted to second in calculateVelocity

  // velocity averaging vars
  const double numVSamples = 1.0;
  int vSampleCount = 0;
  double leftVSampleSum = 0;
  double rightVSampleSum = 0;

  //constants
  const double motorMaxSpeed = 950.0;     //deg / sec


};

#endif

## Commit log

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2017-10-05 Revert "some driver headers"
    This reverts commit 9aa88df013c523bcf91a2107b05c780915e51209.
2017-10-08 Worked on basic sensor headers and stepper headers
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2017-10-08 Changed Stepper Header
    Changed Stepper header to rotate by number of holes and direction
2017-10-09 Added more header files for imu and motorcontroller
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2017-10-25 lays out general framework for the graph structure
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2017-11-20 Made the encoder class, changed up the motorController class, and need to make the encoderReceiver class and connect everything
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2017-12-07 Updated arrayline.h, made arrayline.cpp, updated functions in motorController.cpp, and updated functions in motorController.h
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2017-12-10 Fixed the constructor for motorController
    [motorController.cpp]
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2018-01-30 fixed some errros in node.h
    [Region-5-2017-2018.ino]
2018-01-30 fixed the B to Bl constants
    [Graph.cpp]
2018-01-30 fix some more compile errors
    [Graph.cpp]
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2018-02-02 Token Control File Updates
    Cleaned up TokenControl.cpp, added structure to stepper.cpp and a
    variable to stepper.h
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2018-02-09 fixed header and cpp method names
    [Graph.cpp]
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2018-02-23 debugging, were using too much mem
    [Graph.cpp]
2018-02-27 bug is in Node* adj2[37][8] in graph.cpp
    [Graph.cpp]
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2018-03-02 graph printing correctly
2018-03-08 Intersection Sensors compiles
    Edited intersection sensors to compile, need to calibrate pointline for the field
2018-03-20 Intesection Sensor Works
    1. Changed wiring to get the side line sensors working
    2. Made sure each individual line sensor works
    3. Getting Raw Data from the sensors
2018-03-20 finalizes implementation of the 4 tests outlined in the ppt in notes. Will likely contain bugs and need further testing and tweaking
    [testIntersection.ino]
2018-03-21 missing some adj list entries
    [Graph.cpp, intersectionSensors.cpp, testIntersection.ino]
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2018-03-21 Primary PCB: Added first draft of schematic and PCB.
    [Primary-B.Cu.gbl, Primary-B.Mask.gbs, Primary-B.SilkS.gbo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]
2018-03-21 Primary PCB: Removed one of the I2C bus sockets - we'll only need one.
    [Primary-B.Cu.gbl, Primary-B.Mask.gbs, Primary-B.SilkS.gbo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]
2018-03-21 Motor PCB: Added first draft of schematic.
    [Motor.kicad_pcb, Motor.sch]
2018-03-21 Motor PCB: Created a footprint for the Arduino Nano. Assigned footprints to the components on the Motor schematic.
    [Motor.sch]
2018-03-21 Motor PCB: First draft of PCB.
    [Motor.kicad_pcb, Motor.sch]
2018-03-21 Primary PCB: Added pinout labels and pin labels to silkscreen.
    [Primary-B.Cu.gbl, Primary-B.Mask.gbs, Primary-B.SilkS.gbo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]
2018-03-21 Primary PCB: Regulator screw holes are now plated and connected to GND. Also hid the PX labels for the Arduino headers.
    [Primary-B.Cu.gbl, Primary-B.Mask.gbs, Primary-B.SilkS.gbo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]
2018-03-21 Primary PCB: Power the Arduino with VBATT rather than Regulated 5V.
    [Primary-B.Cu.gbl, Primary-B.Mask.gbs, Primary-B.SilkS.gbo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]
2018-03-21 Motor PCB: Uno is now powered by BATT+; added screw terminal for battery input.
    [Motor.kicad_pcb, Motor.sch]
2018-03-21 Motor PCB: Added silkscreen label for battery and its polarity. Hid PX and UX labels for Arduino headers.
    [Motor.kicad_pcb]
2018-03-21 Motor PCB: Produced PDF Previews of schematic and preview, and gerber files for the PCB.
    [Motor-B.Cu.gbl, Motor-B.SilkS.gbo, Motor-Edge.Cuts.gm1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]
2018-03-22 Motor PCB: Starting over with the board, since we might switch to a Mega.
    [Motor.kicad_pcb, Motor.sch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]
2018-03-22 Motor PCB: Created Mega template project.
    [Motor.kicad_pcb, Motor.sch]
2018-03-22 Motor PCB: Redesigned schematic for the Mega.
    [Motor.sch]
2018-03-22 Motor PCB: Redesigned PCB. Swapped pins for Encoder R's A and B so that layout was easier.
    [Motor.kicad_pcb, Motor.sch]
2018-03-22 Primary/Motor PCBs: Rearranged the GND pin on breakout headers so that we can avoid needing two layers. This change makes the boards more easily prototyped using hobbyist tools like the OtherMill, wh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
    [Motor.kicad_pcb, Motor.sch, Primary.kicad_pcb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]
2018-03-22 Primary/Motor PCBs: Regenerated Gerber files.
    [Motor-B.Cu.gbl, Motor-B.Mask.gbs, Motor-B.SilkS.gbo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]
2018-03-23 Added uno and nano files
    Still need to make the motorcontroller class for the uno file
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2018-03-23 more fixes to token
    [tokenControl.cpp]
2018-03-23 RGB sensor works
    Got RGB sensor to work. Need to improve on the thresholding of the colors. Chad will handle that
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2018-03-26 Primary/Motor PCBs: Added logo and competition to board silkscreens.
    [Motor-B.Cu.gbl, Motor-B.Mask.gbs, Motor-B.SilkS.gbo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]
2018-03-27 fixed a ton of bugs in tokenControl
    [stepper.cpp, tokenControl.cpp]
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2018-03-27 added line sensor code
    we're trying this out using thresholding. Max value is 4. need to test
2018-03-27 fixed syntax errors
    changed syntax erros in Driver file to get it to compile.
    [MotorControl.cpp, MotorControl.h]
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2018-03-28 fixed one bug, testing some other things
    [MotorControl.cpp, MotorControl.h]
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2018-03-28 Changed PID Values
    Removed a way to stop the changing P Value
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2018-03-29 Added Tuning Sweep for PID Constants
    PI values have methods that can be swept over. I wrote a python script to read the output via serial, but we can also just look at the raw serial values which we will do.
2018-03-30 updated the testTokenControl code (all individual parts working, still need to test with magnet attached...)
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2018-03-30 fixed a couple things so we could compile...
    [tokenControl.cpp]
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2018-03-30 Made setMotorMode a lot shorter
    [MotorControl.cpp, MotorControl.h]
2018-03-30 Fixed dumb syntax issues with tokenControl.cpp
    [tokenControl.cpp]
2018-03-30 Fixed compile issue with tokencontrol
    [R5MegaMain.ino, tokenControl.cpp]
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2018-03-30 Addition of turns to set mode for motors and fix for turn direction
    [MotorControl.cpp]
2018-03-30 Compile fixes for my turn commits
    [MotorControl.cpp]
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2018-03-31 Motor PCB: Reduced size to avoid contact with the USB B shell. Redrew right-hand board outline to make it easier for the OtherMill to cut.
    [Motor-B.Cu.gbl, Motor-B.Mask.gbs, Motor-B.SilkS.gbo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]
2018-03-31 Primary PCB: Modified Primary to be more easily printed with labels on the OtherMill.
    [Primary-B.Cu.gbl, Primary-B.Mask.gbs, Primary-B.SilkS.gbo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]
2018-03-31 Motor PCB: Modified PCB to be more easily printed with labels on the OtherMill.
    [Motor-B.Cu.gbl, Motor-B.Mask.gbs, Motor-B.SilkS.gbo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]
2018-03-31 Primary PCB: Modified electromagnet circuit to power the magnet with a transistor.
    [Primary-B.Cu.gbl, Primary-B.Mask.gbs, Primary-B.SilkS.gbo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]
2018-03-31 Motor PCB: Corrected PCB Previews
2018-03-31 Primary PCB: Corrected transistor pinout and footprint. Gave a value to the resistor attached to the transistor.
    [Primary-B.Cu.gbl, Primary-B.Mask.gbs, Primary-B.SilkS.gbo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]
2018-04-01 Added I2C tests
    Added I2C tests. Next we need to actually make sure the commands are the correct commands and then make sure nothing is shorting in the hardware
    [R5MegaDrive.ino, R5MegaMain.ino, driveControl.cpp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]
2018-04-02 Primary PCB: Added Reset button.
    [Primary-B.Cu.gbl, Primary-B.Mask.gbs, Primary-B.SilkS.gbo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]
2018-04-02 fixed misspelled comment, cuz I can
    [R5MegaMain.ino]
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2018-04-03 Changed the diff and added removed pull up resistors
    Changed the diff to 1000
    Removed pull up resistors
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2018-04-04 Changed the values to the correct drive values
    [MotorControl.cpp, R5MegaMain.ino, driveControl.h]
2018-04-04 Added Use array for array on the back
    Added the Use Array so the robot can move without linearray sensors before moving
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2018-04-04 Increased Size of Buffer and Print out Direction
    Increased size of string buffer to 100 for printing values
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2018-04-05 line sensor corrections
2018-04-05 Pins for front arrayline fixed
    [arrayline.cpp, arrayline.h]
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2018-04-06 Revert "Merge branch 'master' of https://github.com/ut-ras/Region-5-2017-2018"
    This reverts commit 037a0fbc4ae76f4c46d67a12c0cc19c0276b78da, reversing
    changes made to b6dbf6b5768469ba93bd185f8e141920d5343d16.
    [MotorControl.cpp]
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2018-04-06 correct dc motor overshoot on stop
    [MotorControl.cpp, MotorControl.h]
2018-04-06 print overshoot
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2018-04-07 Revert "trying without back sensor"
    This reverts commit 3b6d0a35cef63b7431ef620390411f298255c729.
    [MotorControl.cpp]
2018-04-07 MegaMain: Added start/stop button code
    Added functions to wait for start button and check for stop button.
    Initialized pins 2 and 3 as INPUT_PULLUP for start and stop buttons respectively.
2018-04-07 Added polling stop button to Drive and changed stop button in Main to interrupt
2018-04-07 flipped wiring
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2018-04-07 i think this was it, currentCmd with update is buggy
    [MotorControl.cpp]
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
